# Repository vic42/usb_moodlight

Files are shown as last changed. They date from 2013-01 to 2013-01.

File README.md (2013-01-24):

usb_moodlight
=============

The new 0.2 Moodlamp Design featuring a Micro-USB Port

* Circuit Diagram
* PCB Layout
* Firmware

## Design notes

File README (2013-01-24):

Hi, i hope you find this stuff useful. It has been designed as a novice DIY
reflow soldering micro controller execise.

I have included parts of the LUFA library because i needed to modify it
slightly in order to get this project compiled, particularly adding a "-lm"
into lufa_build.mk to include the math lib.

For the beginner, it is much easier to have a project to compile right away
without the need to worry about broken dependencies.

Another thing i had to fix was the cross-avr header that describes the
atmega32u2 because it was incomplete in my distro. I include my version here
for reference. In my distro it goes to /opt/cross/avr/avr/include/avr/iom32u2.h

PREREQUISITES:
==============

1) You will a need cross-avr-gcc toolchain and libc. I used a build from Suse:
   https://build.opensuse.org/project/show?project=CrossToolchain%3Aavr
   to my knowledge, minimum gcc version supporting the 32u2 chip is
   avr-gcc-462 (4.6.2). Any more recent version should suit as well.

2) dfu-programmer
   http://dfu-programmer.sourceforge.net/

BUILD:
======

1) cd USBpwm
2) make && ./flash

! Remember to shortly short the RST and GND lines before flashing, e.g. using
! a metal pencil tip at the right edge of the "ISP" connector.

for the "flash" script to work, you need write permission to the USB port.
Flashing as root user will always work, if in doubt.

RUN:
====

Actually, the last statement within the flash script should have started
your firmware already, provided your USB provides sufficient current for
the circuit. If your USB is limited to the standard 100 mA load, you may
want to pull the "ON" jumper to disconnect the high power LED while
programming.

talking to your moodlight is as easy as this:

screen /dev/ttyACM0

at the time of writing it understands the following commands:

r -> reduce red intensity
R -> increase red intensity
g -> reduce green intensity
G -> increase green intensity
b -> reduce blue intensity
B -> increase blue intensity
h -> reply "# Hello World" (# = incrementing digit)

PLAY:
=====

Have fun and please contribute your improvements!

Peter (vic@ccc.de)

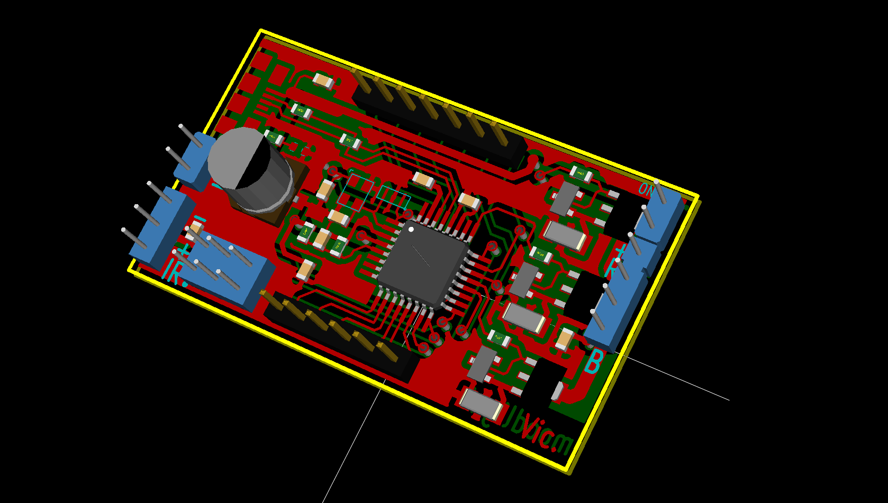
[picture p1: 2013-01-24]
kicad/mood_light.png

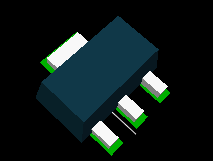
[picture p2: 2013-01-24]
kicad/sot89/SOT89-3D.gif

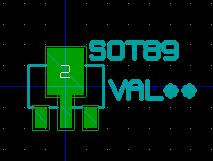
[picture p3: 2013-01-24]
kicad/sot89/SOT89.gif

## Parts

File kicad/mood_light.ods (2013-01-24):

Value | Count | Footprint | References | Comment
100n | 6 | SM0603_Capa | C1, C2, C4, C5, C7, C8
120k | 1 | SM0603 | R1
1k5 | 1 | SM0603 | R11 | Adjust for LED brightness
1R8 | 3 | SM1206 | R6, R9, R10 | Optionally “Mini-MELF”
1uF | 1 | SM0603_Capa | C10
22R | 2 | SM0603 | R3, R4
220µ | 1 | c_elec_6.3x7.7 | C3 | 105° 10V RS 725-8215
22p | 2 | SM0603_Capa | C6, C9 | ONLY required with X1
2K2 | 3 | SM0603 | R5, R7, R8
33k | 1 | SM0603 | R2
ATMEGA32U2 | 1 | TQFP32 | U1
AVR-ISP-6 | 1 | AVR-ISP-6 | CON1 | Optional 3 x 2 x 2.54mm
BCX5616TA | 3 | sot89 | Q2, Q5, Q6
CRYSTAL_4P | 1 | CRYSTAL_3.2x2.5 | X1 | RS 753-7203 [option A] 16 MHz
CSTCE16M0V53-R0 | 1 | CER_OSC | X2 | RS 624-1077 [option B] 16 MHz
IR | 1 | PIN_ARRAY_3X1 | P16 | * 25 x 1 x 2.54mm
LEDS | 1 | PIN_ARRAY_4x1 | P17 | *
LEDS_ON | 1 | PIN_ARRAY_2X1 | JP1 | *
MMBT2222A | 3 | SOT23EBC | Q1, Q3, Q4
PB0 | 1 | PIN_ARRAY_1 | P7 | *
PB4 | 1 | PIN_ARRAY_1 | P11 | *
PB5 | 1 | PIN_ARRAY_1 | P12 | *
PB6 | 1 | PIN_ARRAY_1 | P13 | *
PC7 | 1 | PIN_ARRAY_1 | P14 | *
PD0 | 1 | PIN_ARRAY_1 | P2 | *
PD1 | 1 | PIN_ARRAY_1 | P3 | *
PD2 | 1 | PIN_ARRAY_1 | P4 | *
PD3 | 1 | PIN_ARRAY_1 | P5 | *
PD4 | 1 | PIN_ARRAY_1 | P6 | *
PD5 | 1 | PIN_ARRAY_1 | P10 | *
PD6 | 1 | PIN_ARRAY_1 | P9 | *
PD7 | 1 | PIN_ARRAY_1 | P8 | *
PWR IN | 1 | PIN_ARRAY_2X1 | P1 | *
PWR_LED | 1 | LED-0603 | D1
USB-B-S | 1 | MICRO-B_USB | P15 | RS 714-2344

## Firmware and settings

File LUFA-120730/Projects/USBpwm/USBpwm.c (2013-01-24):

/// 3-Channel Hardware PWM & USB I/O

/// this define is necessary with my gcc/libc combo for some reason
#define __DELAY_BACKWARD_COMPATIBLE__

#include <avr/io.h>
#include <util/delay.h>
#include <avr/interrupt.h>
#include <avr/pgmspace.h>
#include <math.h>

/// LED gamma & max color value
#define GAMMA	2.2
#define	MAXPWM	0xFFFF

/// PWM counter top value
#define CNT_TOP	0xFFFF

/// RGB output pins
#define RED PC6
#define GREEN PC5
#define BLUE PB7

/// color changing speed delay
#define DELAY 10
#define R_SPEED 2
#define G_SPEED 3
#define B_SPEED 5

/// function protos
void init(void);
void setcolor(uint16_t,uint16_t,uint16_t);
int lowvoltage(void);
void helloworld(void);
void mood(void);
void USB_sendstring(char *);
void USB_sendstring_P(PGM_P);
void USB_sendbyte(uint8_t);

#include "USBtoSerial.h"

/** Circular buffer to hold data from the host before it is sent to the device via the serial port. */
static RingBuffer_t USBtoUSART_Buffer;

/** Underlying data buffer for \ref USBtoUSART_Buffer, where the stored bytes are located. */
static uint8_t      USBtoUSART_Buffer_Data[128];

/** Circular buffer to hold data from the serial port before it is sent to the host. */
static RingBuffer_t USARTtoUSB_Buffer;

/** Underlying data buffer for \ref USARTtoUSB_Buffer, where the stored bytes are located. */
static uint8_t      USARTtoUSB_Buffer_Data[128];

/** LUFA CDC Class driver interface configuration and state information. This structure is
 *  passed to all CDC Class driver functions, so that multiple instances of the same class
 *  within a device can be differentiated from one another.
 */
USB_ClassInfo_CDC_Device_t VirtualSerial_CDC_Interface =
	{
		.Config =
			{
				.ControlInterfaceNumber         = 0,
				.DataINEndpoint                 =
					{
						.Address                = CDC_TX_EPADDR,
						.Size                   = CDC_TXRX_EPSIZE,
						.Banks                  = 1,
					},
				.DataOUTEndpoint                =
					{
						.Address                = CDC_RX_EPADDR,
						.Size                   = CDC_TXRX_EPSIZE,
						.Banks                  = 1,
					},
				.NotificationEndpoint           =
					{
						.Address                = CDC_NOTIFICATION_EPADDR,
						.Size                   = CDC_NOTIFICATION_EPSIZE,
						.Banks                  = 1,
					},
			},
	};


/** Main program entry point. This routine contains the overall program flow, including initial
 *  setup of all components and the main program loop.
 */
int main(void)
{
	/// moodlight init
	init();

	/// LUFA init
	SetupHardware();
	RingBuffer_InitBuffer(&USBtoUSART_Buffer, USBtoUSART_Buffer_Data, sizeof(USBtoUSART_Buffer_Data));
	RingBuffer_InitBuffer(&USARTtoUSB_Buffer, USARTtoUSB_Buffer_Data, sizeof(USARTtoUSB_Buffer_Data));
	sei();
	
	/// greetings to the user via USB
	helloworld();
	
	/// main loop
	for (;;)
	{
		mood();
		/* Only try to read in bytes from the CDC interface if the transmit buffer is not full */
		if (!(RingBuffer_IsFull(&USBtoUSART_Buffer)))
		{
			int16_t ReceivedByte = CDC_Device_ReceiveByte(&VirtualSerial_CDC_Interface);

			/* Read bytes from the USB OUT endpoint into the USART transmit buffer */
			if (!(ReceivedByte < 0))
			  RingBuffer_Insert(&USBtoUSART_Buffer, ReceivedByte);
		}

		/* Check if the UART receive buffer flush timer has expired or the buffer is nearly full */
		uint16_t BufferCount = RingBuffer_GetCount(&USARTtoUSB_Buffer);
		if ((TIFR0 & (1 << TOV0)) || (BufferCount > (uint8_t)(sizeof(USARTtoUSB_Buffer_Data) * .75)))
		{
			/* Clear flush timer expiry flag */
			TIFR0 |= (1 << TOV0);

			/* Read bytes from the USART receive buffer into the USB IN endpoint */
			while (BufferCount--)
			{
				/* Try to send the next byte of data to the host, abort if there is an error without dequeuing */
				if (CDC_Device_SendByte(&VirtualSerial_CDC_Interface,
				                        RingBuffer_Peek(&USARTtoUSB_Buffer)) != ENDPOINT_READYWAIT_NoError)
				{
					break;
				}

				/* Dequeue the already sent byte from the buffer now we have confirmed that no transmission error occurred */
				RingBuffer_Remove(&USARTtoUSB_Buffer);
			}
		}
		CDC_Device_USBTask(&VirtualSerial_CDC_Interface);
		USB_USBTask();
	}
}


/************************/
/** moodlight functions */
/************************/

void USB_sendstring(char *s)	/// send string from RAM
{
	while (*s) RingBuffer_Insert(&USARTtoUSB_Buffer, *s++);
}

void USB_sendstring_P(PGM_P s)	/// send string from PROGMEM
{
	uint8_t b;
	while ( b = pgm_read_byte(s++) ) RingBuffer_Insert(&USARTtoUSB_Buffer, b);
}

void USB_sendbyte(uint8_t byte)	/// send byte
{
	RingBuffer_Insert(&USARTtoUSB_Buffer, byte);
}

void helloworld(void)	/// "# Hello World" to host via USB ;-)
{
	static uint8_t num=0;

	USB_sendbyte('0' + num++);
	USB_sendstring_P(PSTR(" Hello World\r\n"));
	num %= 10;
}

void mood(void)
{
	static uint8_t command;
	static uint16_t i=0;
	static uint16_t r=MAXPWM,g=MAXPWM/2,b=MAXPWM/42;
	static uint16_t r_dir=R_SPEED, g_dir=G_SPEED, b_dir=B_SPEED;

	command='m';	// default command: mood
	
	/* Load the next command byte from the USB to USART transmit buffer */
	if (!(RingBuffer_IsEmpty(&USBtoUSART_Buffer)))
		  command=RingBuffer_Remove(&USBtoUSART_Buffer);
	switch (command) {
		case 'r': if (r >=1000) r-=1000; break;
		case 'R': if (r <= MAXPWM-1000) r+=1000; break;
		case 'g': if (g >=1000) g-=1000; break;
		case 'G': if (g <= MAXPWM-1000) g+=1000; break;
		case 'b': if (b >=1000) b-=1000; break;
		case 'B': if (b <= MAXPWM-1000) b+=1000; break;
		case 'h': helloworld();
		default:
			if (++i > DELAY) {
				if (r >= (MAXPWM - R_SPEED)) r_dir = -R_SPEED;
				if (r <= R_SPEED) r_dir = R_SPEED;
				if (g >= (MAXPWM - G_SPEED)) g_dir = -G_SPEED;
				if (g <= G_SPEED) g_dir = G_SPEED;
				if (b >= (MAXPWM - B_SPEED)) b_dir = -B_SPEED;
				if (b <= B_SPEED) b_dir = B_SPEED;
				r += r_dir; g += g_dir; b += b_dir;
				setcolor(r,g,b);
				if (lowvoltage()) {	// red light and stop
					setcolor(MAXPWM,0,0);
					for(;;);
				}
				i=0;
			}
	}
}

/*************************************************/
/** actual setup routines for the moodlight part */
/*************************************************/

void init(void)		// setup stuff
{
	// setup system clock
	cli();			// do not interrupt clock frequency changes
	CLKPR = (1 << CLKPCE);	// enable clock prescaler update
	CLKPR = 0;		// set clock to maximum (= crystal)
	// set alternate pin functions for RGB pins (clear on compare match [10])
	TCCR1A = (1 << COM1A1) | (1 << COM1B1) | (1 << COM1C1);
	// setup timer1 for Fast PWM mode 14 (TOP=ICR1)
	TCCR1A |= (1 << WGM11);	// WGM bits are split across TCCR1A and TCCR1B
	TCCR1B |= (1 << WGM12) | (1 << WGM13);
	// select clock source and set divider to 1 (244 Hz 16-bit PWM)
	TCCR1B |= (1 << CS10);
	// setup ICR1 for counter TOP value
	ICR1 = CNT_TOP;
	// set direction of rgb ports to output
	DDRC |= (1 << RED);
	DDRC |= (1 << GREEN);
	DDRB |= (1 << BLUE);

	// analog input setup (interrupt on falling edge, bandgap reference)
	ACSR = (1 << ACBG) | (1 << ACIS1);
	// analoc comparator mux - select AIN2, disable digital input
	ACMUX = (1 << CMUX0);
	DIDR1 = (1 << AIN2D);
	// clear pending undervoltage interrupt
	ACSR |= (1 << ACI);
}

void setcolor(uint16_t r,uint16_t g,uint16_t b)	// set a new RGB color
{
	OCR1A = round((double) (CNT_TOP) * pow(((double) r / (double) (MAXPWM)) , GAMMA));
	OCR1B = round((double) (CNT_TOP) * pow(((double) g / (double) (MAXPWM)) , GAMMA));
	OCR1C = round((double) (CNT_TOP) * pow(((double) b / (double) (MAXPWM)) , GAMMA));
}

int lowvoltage(void)	// check if voltage ok [0] or low [1]
{
	if ( (ACSR & (1 << ACI)) == 0 ) return 0;	// no brownout occured
	ACSR |= (1 << ACI);	// clear pending undervoltage interrupt
	return 1;
}


/** Configures the board hardware and chip peripherals for the demo's functionality. */
void SetupHardware(void)
{
	/* Hardware Initialization */
	USB_Init();

	/* Start the flush timer so that overflows occur rapidly to push received bytes to the USB interface */
	TCCR0B = (1 << CS02);
}

/** Event handler for the library USB Connection event. */
void EVENT_USB_Device_Connect(void)
{
}

/** Event handler for the library USB Disconnection event. */
void EVENT_USB_Device_Disconnect(void)
{
}

/** Event handler for the library USB Configuration Changed event. */
void EVENT_USB_Device_ConfigurationChanged(void)
{
	bool ConfigSuccess = true;

	ConfigSuccess &= CDC_Device_ConfigureEndpoints(&VirtualSerial_CDC_Interface);
}

/** Event handler for the library USB Control Request reception event. */
void EVENT_USB_Device_ControlRequest(void)
{
	CDC_Device_ProcessControlRequest(&VirtualSerial_CDC_Interface);
}

/** ISR to manage the reception of data from the serial port, placing received bytes into a circular buffer
 *  for later transmission to the host.
 */
//ISR(USART1_RX_vect, ISR_BLOCK)
//{
//}

/** Event handler for the CDC Class driver Line Encoding Changed event.
 *
 *  \param[in] CDCInterfaceInfo  Pointer to the CDC class interface configuration structure being referenced
 */
void EVENT_CDC_Device_LineEncodingChanged(USB_ClassInfo_CDC_Device_t* const CDCInterfaceInfo)
{
}

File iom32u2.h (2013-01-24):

/* Copyright (c) 2009 Atmel Corporation
   All rights reserved.

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
   * Neither the name of the copyright holders nor the names of
     contributors may be used to endorse or promote products derived
     from this software without specific prior written permission.

  THIS SOFTWARE IS PROVIDED BY THE COPYRIGHT HOLDERS AND CONTRIBUTORS "AS IS"
  AND ANY EXPRESS OR IMPLIED WARRANTIES, INCLUDING, BUT NOT LIMITED TO, THE
  IMPLIED WARRANTIES OF MERCHANTABILITY AND FITNESS FOR A PARTICULAR PURPOSE
  ARE DISCLAIMED. IN NO EVENT SHALL THE COPYRIGHT OWNER OR CONTRIBUTORS BE
  LIABLE FOR ANY DIRECT, INDIRECT, INCIDENTAL, SPECIAL, EXEMPLARY, OR
  CONSEQUENTIAL DAMAGES (INCLUDING, BUT NOT LIMITED TO, PROCUREMENT OF
  SUBSTITUTE GOODS OR SERVICES; LOSS OF USE, DATA, OR PROFITS; OR BUSINESS
  INTERRUPTION) HOWEVER CAUSED AND ON ANY THEORY OF LIABILITY, WHETHER IN
  CONTRACT, STRICT LIABILITY, OR TORT (INCLUDING NEGLIGENCE OR OTHERWISE)
  ARISING IN ANY WAY OUT OF THE USE OF THIS SOFTWARE, EVEN IF ADVISED OF THE
  POSSIBILITY OF SUCH DAMAGE. */

/* $Id: iom32u2.h 2240 2011-05-09 22:18:18Z arcanum $ */

/* avr/iom32u2.h - definitions for ATmega32U2 */

/* This file should only be included from <avr/io.h>, never directly. */

#ifndef _AVR_IO_H_
#  error "Include <avr/io.h> instead of this file."
#endif

#ifndef _AVR_IOXXX_H_
#  define _AVR_IOXXX_H_ "iom32u2.h"
#else
#  error "Attempt to include more than one <avr/ioXXX.h> file."
#endif 


#ifndef _AVR_ATmega32U2_H_
#define _AVR_ATmega32U2_H_ 1


/* Registers and associated bit numbers. */

#define PINB _SFR_IO8(0x03)
#define PINB0 0
#define PINB1 1
#define PINB2 2
#define PINB3 3
#define PINB4 4
#define PINB5 5
#define PINB6 6
#define PINB7 7

#define DDRB _SFR_IO8(0x04)
#define DDB0 0
#define DDB1 1
#define DDB2 2
#define DDB3 3
#define DDB4 4
#define DDB5 5
#define DDB6 6
#define DDB7 7

#define PORTB _SFR_IO8(0x05)
#define PORTB0 0
#define PORTB1 1
#define PORTB2 2
#define PORTB3 3
#define PORTB4 4
#define PORTB5 5
#define PORTB6 6
#define PORTB7 7

#define PINC _SFR_IO8(0x06)
#define PINC0 0
#define PINC1 1
#define PINC2 2
#define PINC4 4
#define PINC5 5
#define PINC6 6
#define PINC7 7

#define DDRC _SFR_IO8(0x07)
#define DDC0 0
#define DDC1 1
#define DDC2 2
#define DDC4 4
#define DDC5 5
#define DDC6 6
#define DDC7 7

#define PORTC _SFR_IO8(0x08)
#define PORTC0 0
#define PORTC1 1
#define PORTC2 2
#define PORTC4 4
#define PORTC5 5
#define PORTC6 6
#define PORTC7 7

#define PIND _SFR_IO8(0x09)
#define PIND0 0
#define PIND1 1
#define PIND2 2
#define PIND3 3
#define PIND4 4
#define PIND5 5
#define PIND6 6
#define PIND7 7

#define DDRD _SFR_IO8(0x0A)
#define DDD0 0
#define DDD1 1
#define DDD2 2
#define DDD3 3
#define DDD4 4
#define DDD5 5
#define DDD6 6
#define DDD7 7

#define PORTD _SFR_IO8(0x0B)
#define PORTD0 0
#define PORTD1 1
#define PORTD2 2
#define PORTD3 3
#define PORTD4 4
#define PORTD5 5
#define PORTD6 6
#define PORTD7 7

#define TIFR0 _SFR_IO8(0x15)
#define TOV0 0
#define OCF0A 1
#define OCF0B 2

#define TIFR1 _SFR_IO8(0x16)
#define TOV1 0
#define OCF1A 1
#define OCF1B 2
#define OCF1C 3
#define ICF1 5

#define PCIFR _SFR_IO8(0x1B)
#define PCIF0 0
#define PCIF1 1

#define EIFR _SFR_IO8(0x1C)
#define INTF0 0
#define INTF1 1
#define INTF2 2
#define INTF3 3
#define INTF4 4
#define INTF5 5
#define INTF6 6
#define INTF7 7

#define EIMSK _SFR_IO8(0x1D)
#define INT0 0
#define INT1 1
#define INT2 2
#define INT3 3
#define INT4 4
#define INT5 5
#define INT6 6
#define INT7 7

#define GPIOR0 _SFR_IO8(0x1E)
#define GPIOR00 0
#define GPIOR01 1
#define GPIOR02 2
#define GPIOR03 3
#define GPIOR04 4
#define GPIOR05 5
#define GPIOR06 6
#define GPIOR07 7

#define EECR _SFR_IO8(0x1F)
#define EERE 0
#define EEPE 1
#define EEMPE 2
#define EERIE 3
#define EEPM0 4
#define EEPM1 5

#define EEDR _SFR_IO8(0x20)
#define EEDR0 0
#define EEDR1 1
#define EEDR2 2
#define EEDR3 3
#define EEDR4 4
#define EEDR5 5
#define EEDR6 6
#define EEDR7 7

#define EEAR _SFR_IO16(0x21)

#define EEARL _SFR_IO8(0x21)
#define EEAR0 0
#define EEAR1 1
#define EEAR2 2
#define EEAR3 3
#define EEAR4 4
#define EEAR5 5
#define EEAR6 6
#define EEAR7 7

#define EEARH _SFR_IO8(0x22)
#define EEAR8 0
#define EEAR9 1
#define EEAR10 2
#define EEAR11 3

#define GTCCR _SFR_IO8(0x23)
#define PSRSYNC 0
#define TSM 7

#define TCCR0A _SFR_IO8(0x24)
#define WGM00 0
#define WGM01 1
#define COM0B0 4
#define COM0B1 5
#define COM0A0 6
#define COM0A1 7

#define TCCR0B _SFR_IO8(0x25)
#define CS00 0
#define CS01 1
#define CS02 2
#define WGM02 3
#define FOC0B 6
#define FOC0A 7

#define TCNT0 _SFR_IO8(0x26)
#define TCNT0_0 0
#define TCNT0_1 1
#define TCNT0_2 2
#define TCNT0_3 3
#define TCNT0_4 4
#define TCNT0_5 5
#define TCNT0_6 6
#define TCNT0_7 7

#define OCR0A _SFR_IO8(0x27)
#define OCR0A_0 0
#define OCR0A_1 1
#define OCR0A_2 2
#define OCR0A_3 3
#define OCR0A_4 4
#define OCR0A_5 5
#define OCR0A_6 6
#define OCR0A_7 7

#define OCR0B _SFR_IO8(0x28)
#define OCR0B_0 0
#define OCR0B_1 1
#define OCR0B_2 2
#define OCR0B_3 3
#define OCR0B_4 4
#define OCR0B_5 5
#define OCR0B_6 6
#define OCR0B_7 7

#define PLLCSR _SFR_IO8(0x29)
#define PLOCK 0
#define PLLE 1
#define PLLP0 2
#define PLLP1 3
#define PLLP2 4

#define GPIOR1 _SFR_IO8(0x2A)
#define GPIOR10 0
#define GPIOR11 1
#define GPIOR12 2
#define GPIOR13 3
#define GPIOR14 4
#define GPIOR15 5
#define GPIOR16 6
#define GPIOR17 7

#define GPIOR2 _SFR_IO8(0x2B)
#define GPIOR20 0
#define GPIOR21 1
#define GPIOR22 2
#define GPIOR23 3
#define GPIOR24 4
#define GPIOR25 5
#define GPIOR26 6
#define GPIOR27 7

#define SPCR _SFR_IO8(0x2C)
#define SPR0 0
#define SPR1 1
#define CPHA 2
#define CPOL 3
#define MSTR 4
#define DORD 5
#define SPE 6
#define SPIE 7

#define SPSR _SFR_IO8(0x2D)
#define SPI2X 0
#define WCOL 6
#define SPIF 7

#define SPDR _SFR_IO8(0x2E)
#define SPDR0 0
#define SPDR1 1
#define SPDR2 2
#define SPDR3 3
#define SPDR4 4
#define SPDR5 5
#define SPDR6 6
#define SPDR7 7

#define ACSR _SFR_IO8(0x30)
#define ACIS0 0
#define ACIS1 1
#define ACIC 2
#define ACIE 3
#define ACI 4
#define ACO 5
#define ACBG 6
#define ACD 7

#define DWDR _SFR_IO8(0x31)
#define DWDR0 0
#define DWDR1 1
#define DWDR2 2
#define DWDR3 3
#define DWDR4 4
#define DWDR5 5
#define DWDR6 6
#define DWDR7 7

#define SMCR _SFR_IO8(0x33)
#define SE 0
#define SM0 1
#define SM1 2
#define SM2 3

#define MCUSR _SFR_IO8(0x34)
#define PORF 0
#define EXTRF 1
#define BORF 2
#define WDRF 3
#define USBRF 5

#define MCUCR _SFR_IO8(0x35)
#define IVCE 0
#define IVSEL 1
#define PUD 4

#define SPMCSR _SFR_IO8(0x37)
#define SPMEN 0
#define PGERS 1
#define PGWRT 2
#define BLBSET 3
#define RWWSRE 4
#define SIGRD 5
#define RWWSB 6
#define SPMIE 7

#define EIND _SFR_IO8(0x3C)
#define EIND0 0

#define WDTCSR _SFR_MEM8(0x60)
#define WDP0 0
#define WDP1 1
#define WDP2 2
#define WDE 3
#define WDCE 4
#define WDP3 5
#define WDIE 6
#define WDIF 7

#define CLKPR _SFR_MEM8(0x61)
#define CLKPS0 0
#define CLKPS1 1
#define CLKPS2 2
#define CLKPS3 3
#define CLKPCE 7
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
